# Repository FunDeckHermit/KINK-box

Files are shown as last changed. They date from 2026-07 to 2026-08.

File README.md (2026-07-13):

# KINK-box

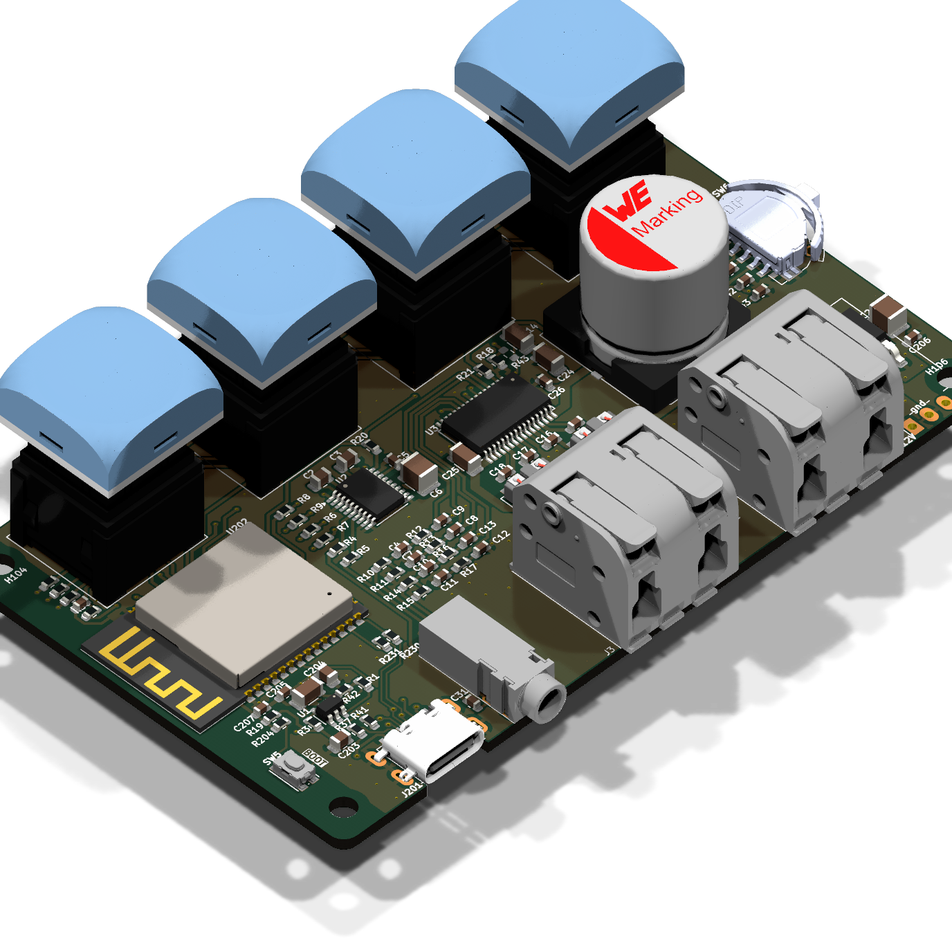
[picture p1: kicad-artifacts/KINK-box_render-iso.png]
KINK-box Isometric Render


A compact USB-C-powered stereo audio player and amplifier powered by an ESP32-S3 microcontroller.

## Overview

KINK-box is a dedicated audio playback device with built-in amplification, WiFi connectivity, and a simple web interface. Stream audio to speakers or headphones with intuitive physical and web controls.

## Features

- **USB-C Power Delivery**: Powered by standard USB-C PD adapter (12V negotiated)
- **WiFi Connectivity**: Built-in 2.4 GHz WiFi for streaming
- **Web Interface**: Control playback and configuration from any browser
- **Stereo Audio Output**: 
  - Speaker terminals for direct loudspeaker connection
  - 3.5mm line-level jack for headphones or external amplifiers
- **Physical Controls**: 
  - Four RGB-illuminated buttons for quick access
  - Additional tactile button and navigation switch for volume and menu control
- **Class-D Amplifier**: High-efficiency 30W stereo amplifier built-in

## Quick Start

1. **Assembly**: Reference the component placement guide and [Bill of Materials](kicad-artifacts/KINK-box_bom.csv)
2. **Power On**: Connect a USB-C Power Delivery adapter
3. **Connect**: Join the device WiFi network
4. **Access**: Open `http://<device-ip>` in your browser
5. **Play**: Use the web interface or physical buttons to select and play audio
6. **Volume**: Adjust using physical controls or the web interface

## Hardware Files

All manufacturing and design files are in `kicad-artifacts/`:
- **Gerbers**: `KINK-box_gerbers.zip` - For PCB fabrication
- **Schematics**: `KINK-box_schematic.pdf`
- **3D Model**: `KINK-box_board.step`
- **Interactive BOM**: `ibom.html`

## License

Apache License 2.0 - see [LICENSE](LICENSE) for details.

---

**KINK-box** - Simple stereo audio player with built-in amplification and WiFi.

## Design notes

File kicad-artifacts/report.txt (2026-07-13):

KiCad Export Report
===================

Project: KINK-box
Run at: 2026-07-13 19:25:50
Duration: 31s
KiCad Type: Flatpak

Render settings:
  Quality: high
  Resolution: 1400x1400
  Isometric rotation: 315,0,45

Gerber layers:
  F.Cu,B.Cu,F.Mask,B.Mask,F.Paste,B.Paste,F.SilkS,B.SilkS,Edge.Cuts

Drill:
  Format: Excellon
  Map: PDF

Placement:
  Format: CSV
  Units: mm
  Side: both

Interactive BOM:
  Fields: Value, Footprint, MF, MPN
  Grouped by: Value, Footprint
  DNP filtering: Enabled (kicad_dnp field)
  Layout: left-right
  Layer view: Front

Generated files:
build.log
drill
ibom.html
KINK-box_board.step
KINK-box_bom.csv
KINK-box_gerbers.zip
KINK-box_pcb.pdf
KINK-box_placement.csv
KINK-box_render-bottom.png
KINK-box_render-iso.png
KINK-box_render-top.png
KINK-box_schematic.pdf

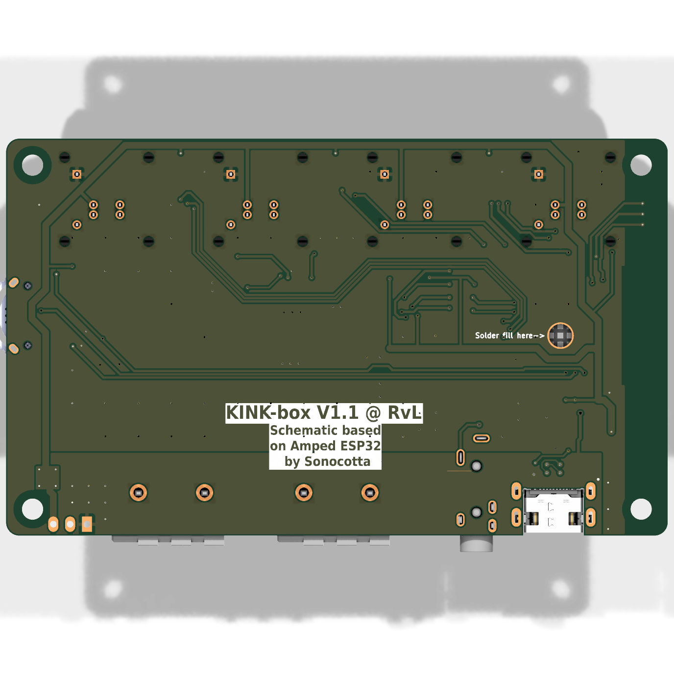
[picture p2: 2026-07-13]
kicad-artifacts/KINK-box_render-bottom.png

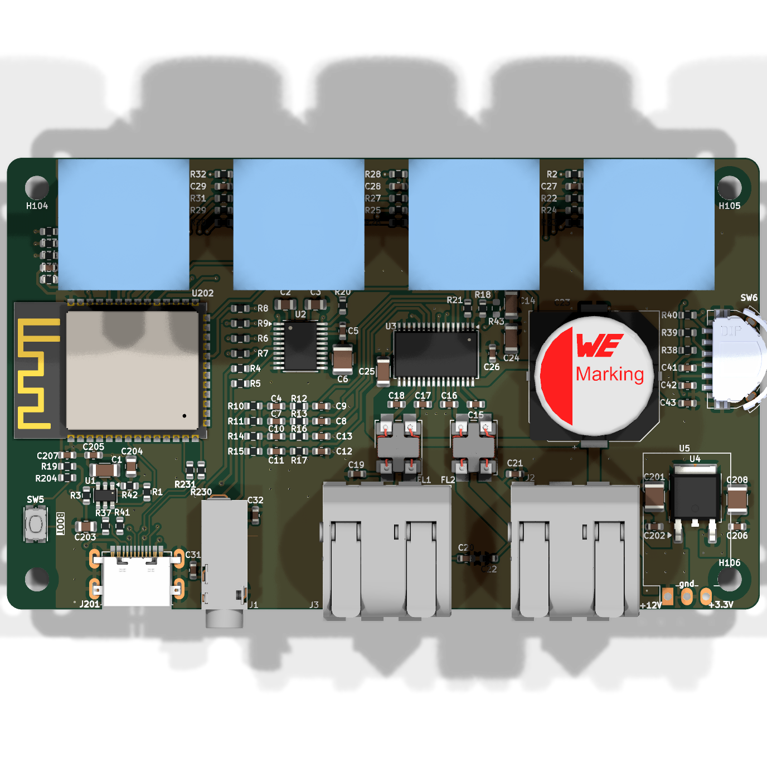
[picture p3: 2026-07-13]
kicad-artifacts/KINK-box_render-top.png

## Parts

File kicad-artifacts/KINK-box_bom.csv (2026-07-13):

Designator | Comment | MPN | Footprint | Quantity
C1,C4,C7,C10,C11,C14 | 1uF | 0603B105K100CT,1206B105K250CT | Capacitor_SMD:C_0603_1608Metric,Capacitor_SMD:C_1206_3216Metric | 6
C2,C3 | 2.2uF | 0805B225K250CT | Capacitor_SMD:C_0805_2012Metric | 2
C5,C15,C16,C17,C18,C26,C27,C28,C29,C30,C41,C42,C43,C202,C205,C206,C207 | 100nF | 0603B104K500CT | Capacitor_SMD:C_0603_1608Metric | 17
C6,C24,C25,C201,C203,C204,C208 | 10uF | 1206B106K250CT | Capacitor_SMD:C_0805_2012Metric,Capacitor_SMD:C_1206_3216Metric,Capacitor_SMD:C_1210_3225Metric | 7
C8,C9,C12,C13 | 220nF | 0603B224K500CT | Capacitor_SMD:C_0603_1608Metric | 4
C19,C20,C21,C22 | 680nF | 0603B684K100CT | Capacitor_SMD:C_0603_1608Metric | 4
C23 | 470uF | 865060663013 | 0_NRD_footprints:CP_Wurth_WCAP-ASLL-D16L17 | 1
C31,C32 | 2.2nF | 0603B222K500CT | Capacitor_SMD:C_0603_1608Metric | 2
FL1,FL2 | 744238701 | 744238701 | 0_NRD_footprints:L_Wurth_WE-CMDC-7060 | 2
H103,H104,H105,H106 | MountingHole |  | MountingHole:MountingHole_3.2mm_M3 | 4
J1 | PJ-328A0-B | PJ-328A0-B | 0_NRD_footprints:PJ-328A0-B | 1
J2,J3 | QT02CSF83H0000G | QT02CSF83H0000G | 0_NRD_footprints:QT02CSF83H0000G | 2
J201 | USB4500-03-0-A |  | _projectlib:USB_C_Receptacle_USB4500-03-0-A | 1
R1,R2,R3,R28,R32,R36,R38,R39,R40 | 47K | RC0603FR-0747KL | Resistor_SMD:R_0603_1608Metric | 9
R4,R5,R6,R7,R8 | 470R | RC0603FR-07470RL | Resistor_SMD:R_0603_1608Metric | 5
R9,R10,R11,R14,R15 | 10K | RC0603FR-0710KL | Resistor_SMD:R_0603_1608Metric | 5
R12,R13,R16,R17,R204 | 1K0 | RC0603FR-07FRE131KL | Resistor_SMD:R_0603_1608Metric | 5
R18 | 5K6 | RC0603FR-075K6L | Resistor_SMD:R_0603_1608Metric | 1
R19,R20,R21 | 22K | RC0603FR-0722KL | Resistor_SMD:R_0603_1608Metric | 3
R22,R23,R24,R25,R26,R27,R29,R30,R31,R33,R34,R35 | 220R | RC0603FR-07220RL | Resistor_SMD:R_0603_1608Metric | 12
R37,R41,R42 | 5K1 | RC0603FR-075K1L | Resistor_SMD:R_0603_1608Metric | 3
R230,R231 | 22R |  | Resistor_SMD:R_0603_1608Metric | 2
SW1,SW2,SW3,SW4 | 465M111172501 |  | 0_NRD_footprints:SW_Wurth_WS-PBTL_465M111172501 | 4
SW5 | KMR223GLFG | KMR223GLFG | 0_NRD_footprints:SW_Push_1P1T_NO_CK_KMR2 | 1
SW6 |  | PLMG5-GH-V-T/R | 0_NRD_footprints:SW_PLMG5-GH | 1
U1 | CH221K |  | Package_TO_SOT_SMD:SOT-23-6 | 1
U2 | PCM5100A |  | Package_SO:TSSOP-20_4.4x6.5mm_P0.65mm | 1
U3 | TPA3118D2DAPR | TPA3118D2DAPR | Package_SO:HTSSOP-32-1EP_6.1x11mm_P0.65mm_EP5.2x11mm_Mask4.11x4.36mm | 1
U4 | BD33FC0FP | BD33FC0FP-E2 | Package_TO_SOT_SMD:TO-252-2 | 1
U202 | ESP32-S3-WROOM-1 |  | _projectlib:ESP32-S3-WROOM-1 | 1

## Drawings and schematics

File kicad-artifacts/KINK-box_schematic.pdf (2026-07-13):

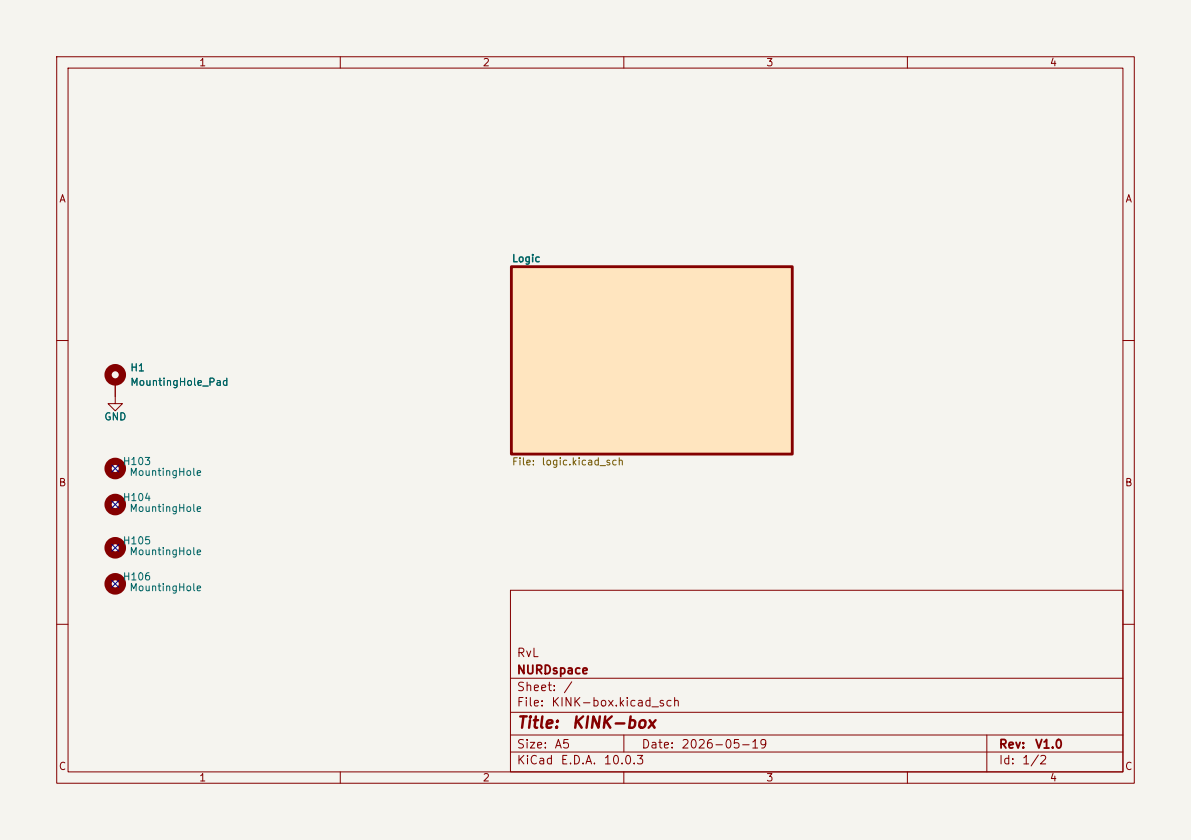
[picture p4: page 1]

File: logic.kicad_sch GNDH105 MountingHole H104 MountingHole H103 MountingHole H1MountingHole_Pad H106 MountingHole

Size: A5 | Rev: V1.0 | C Date: 2026-05-19
KiCad E.D.A. 10.0.3 | Id: 1/2

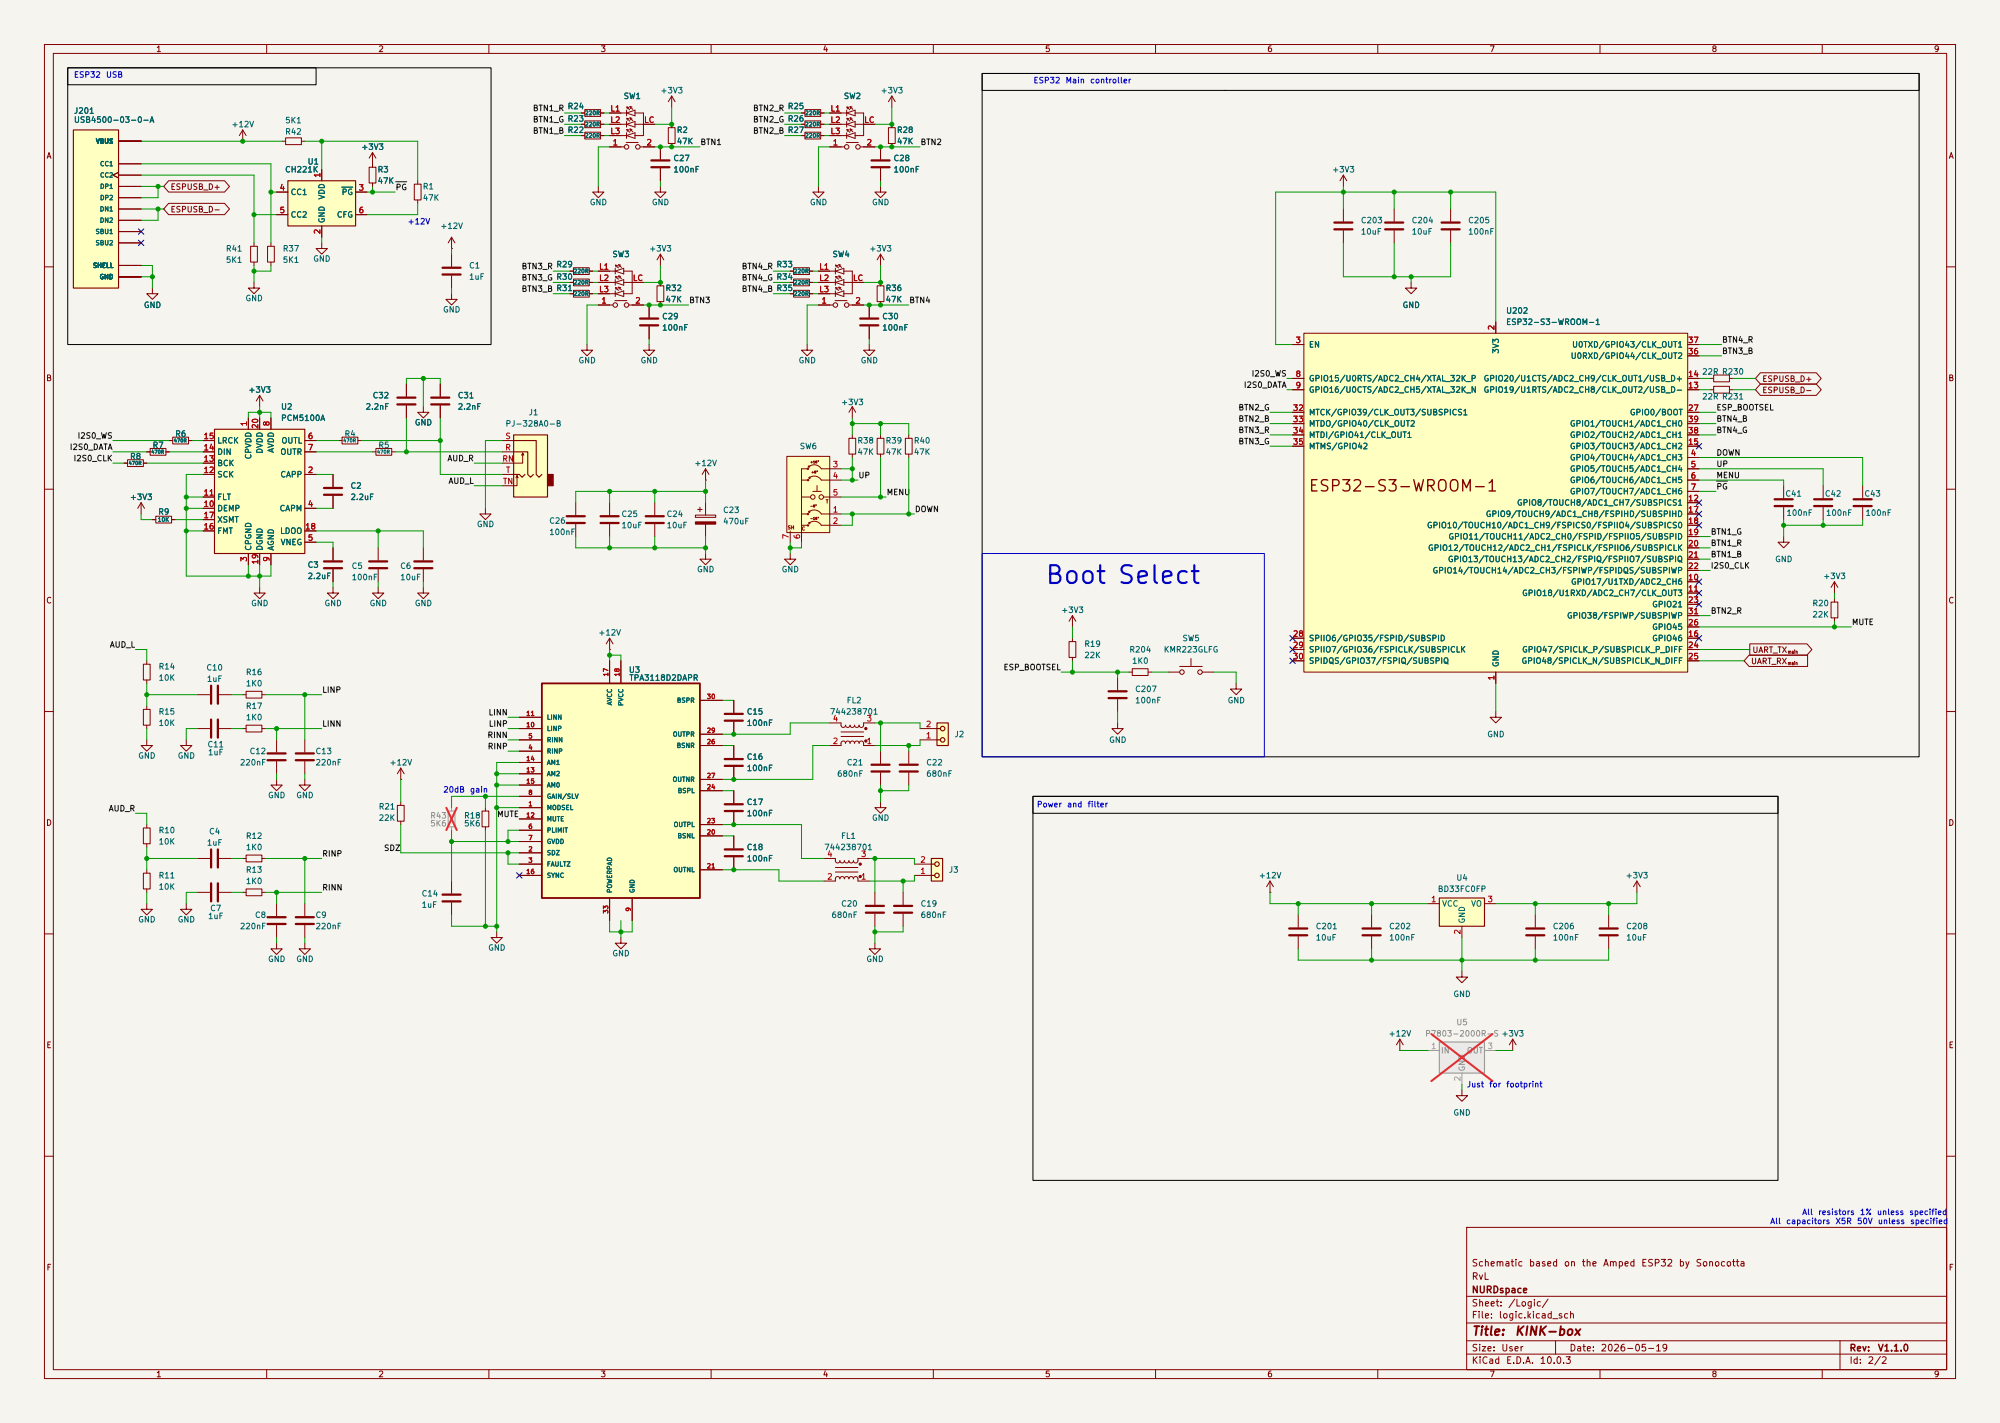
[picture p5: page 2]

ESP32 Main controller Boot Select

SCK 12 BCK 13 DIN 14 LRCK 15

All capacitors X5R 50V unless specified C18

Schematic based on the Amped ESP32 by Sonocotta
RvL
NURDspace
Sheet: /Logic/
File: logic.kicad_sch
Title: KINK-box

Size: User | Rev: V1.1.0
KiCad E.D.A. 10.0.3 | Id: 2/2

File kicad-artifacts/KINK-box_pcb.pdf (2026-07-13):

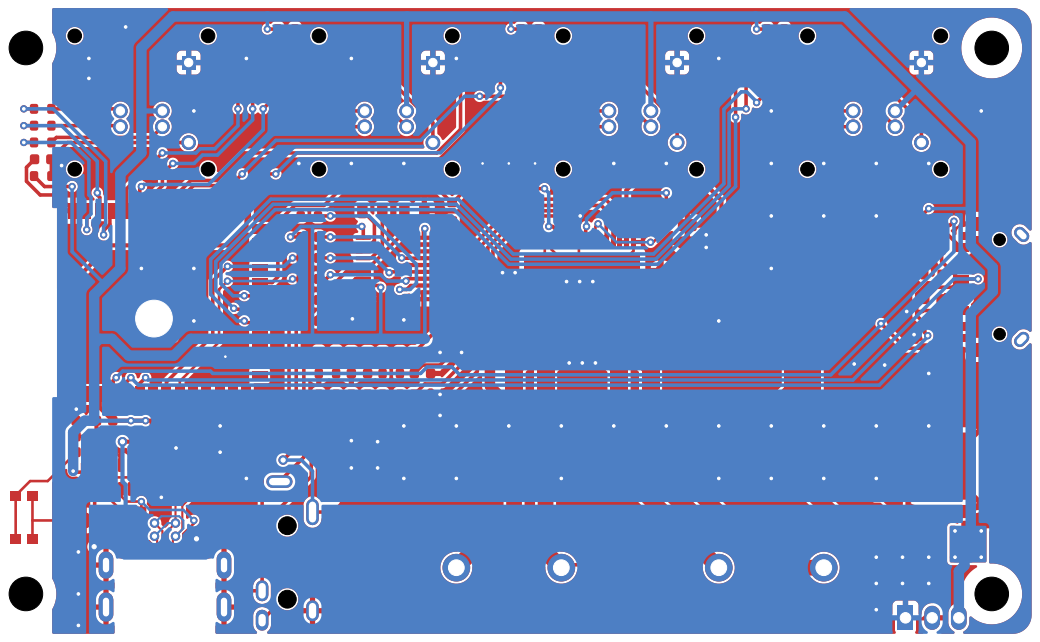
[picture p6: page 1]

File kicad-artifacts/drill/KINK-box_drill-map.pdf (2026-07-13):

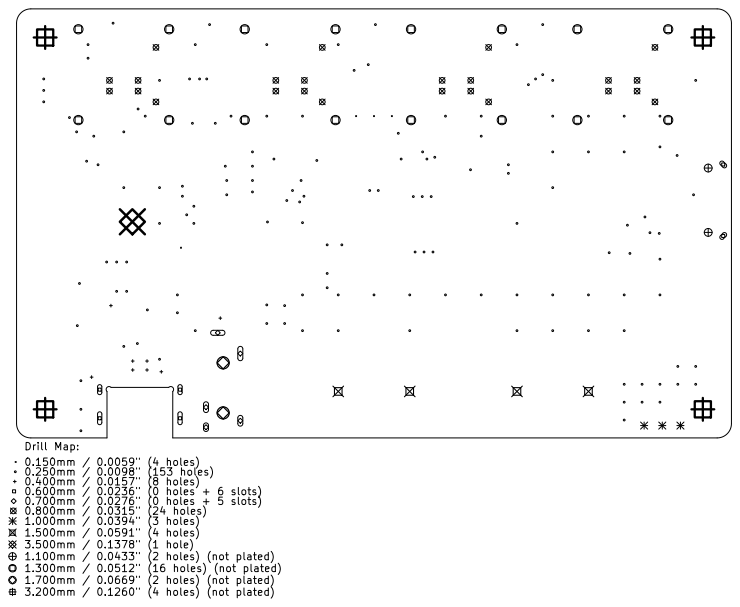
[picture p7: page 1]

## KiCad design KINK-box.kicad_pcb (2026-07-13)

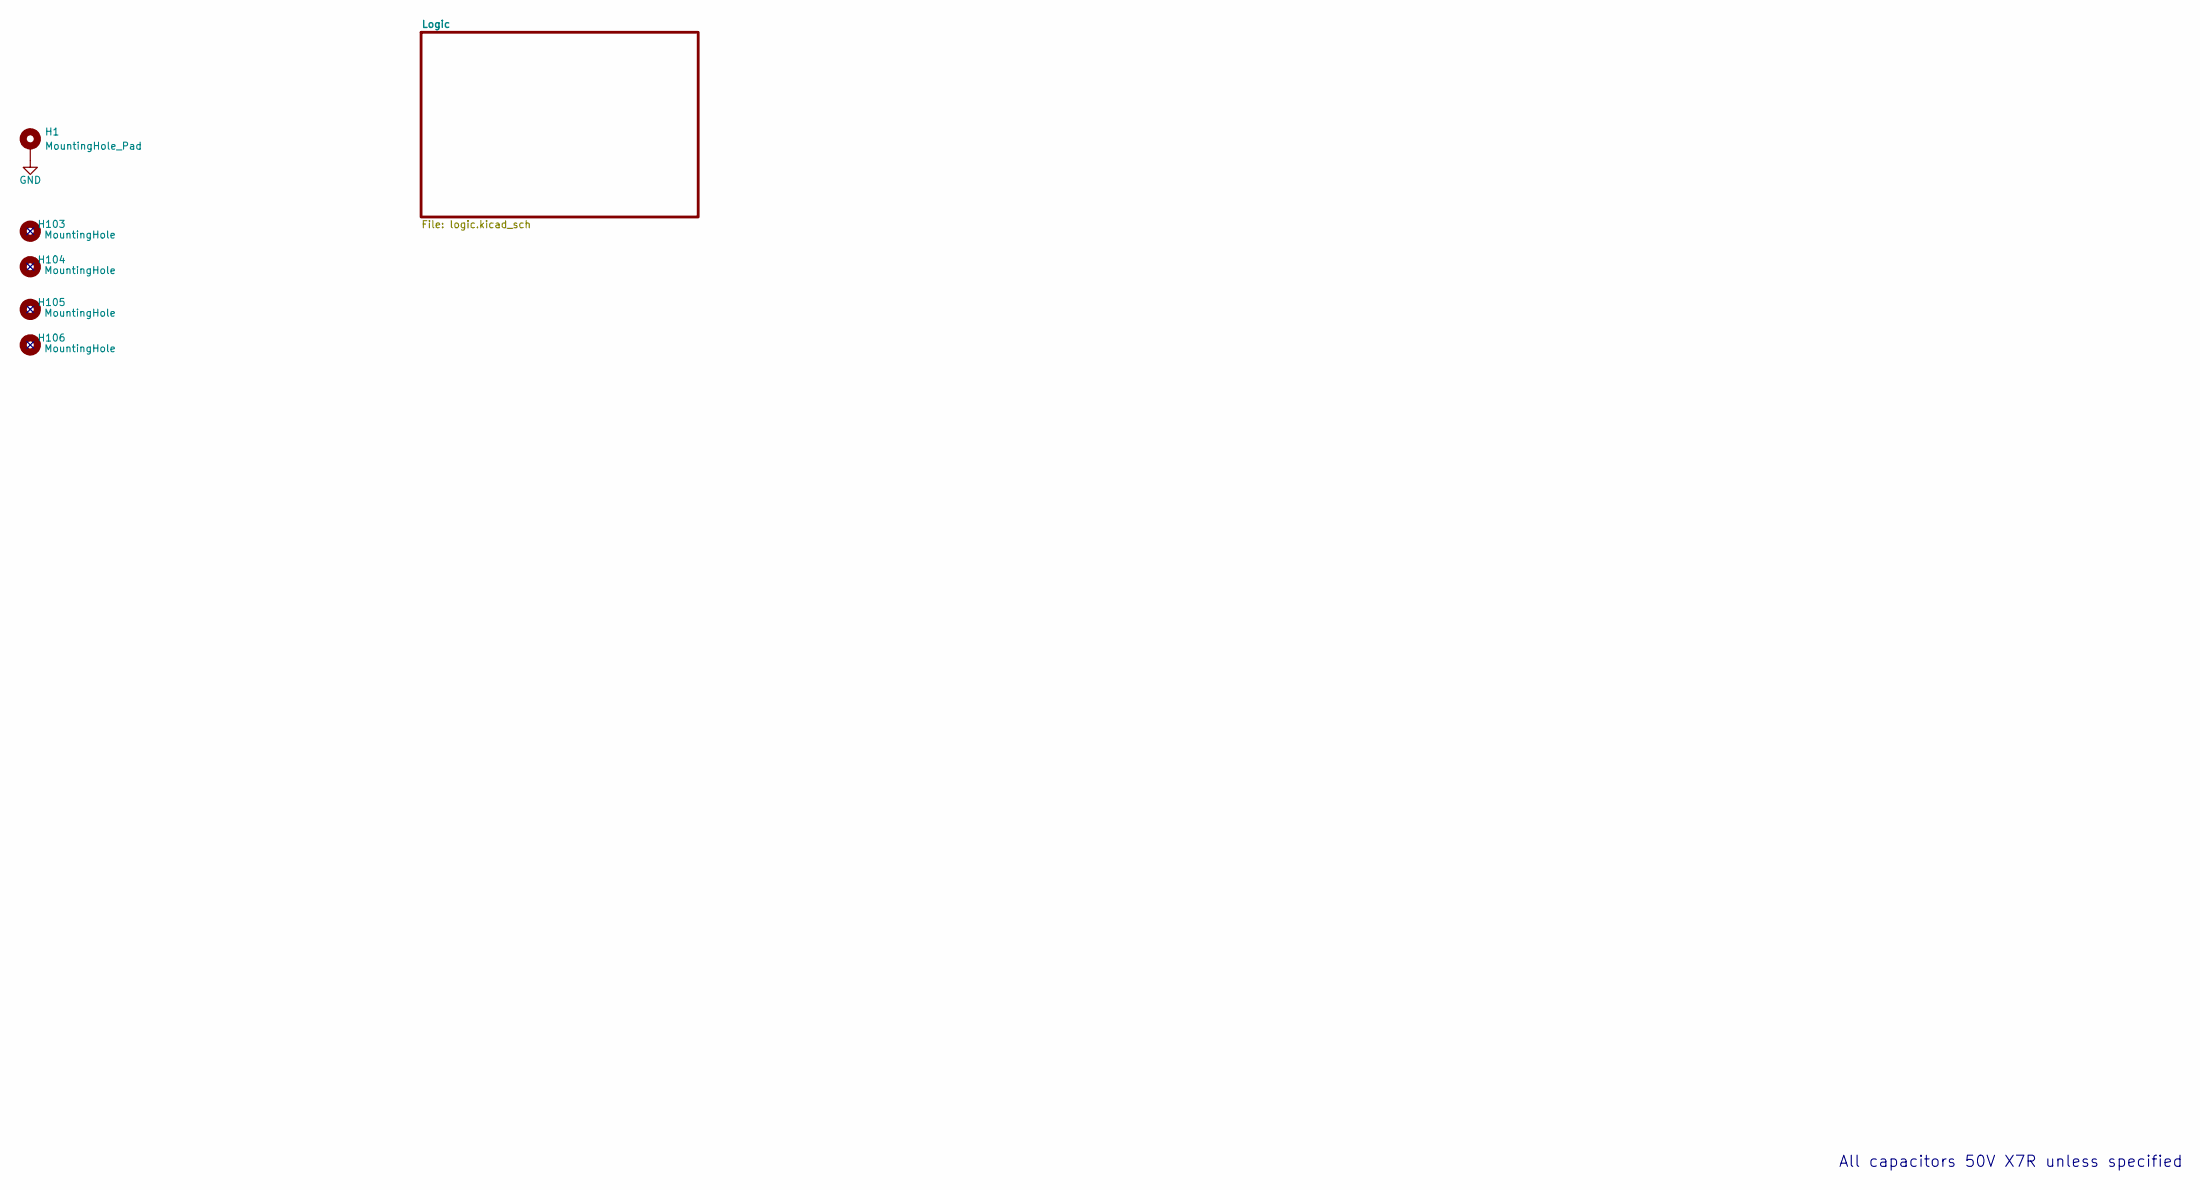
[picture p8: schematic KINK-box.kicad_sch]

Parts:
H1: MountingHole_Pad; ESP-solderhole
H103, H104, H105, H106: MountingHole; MountingHole_3.2mm_M3

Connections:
GND: H1.1 (1_1); also elsewhere on the board

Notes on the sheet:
All capacitors 50V X7R unless specified

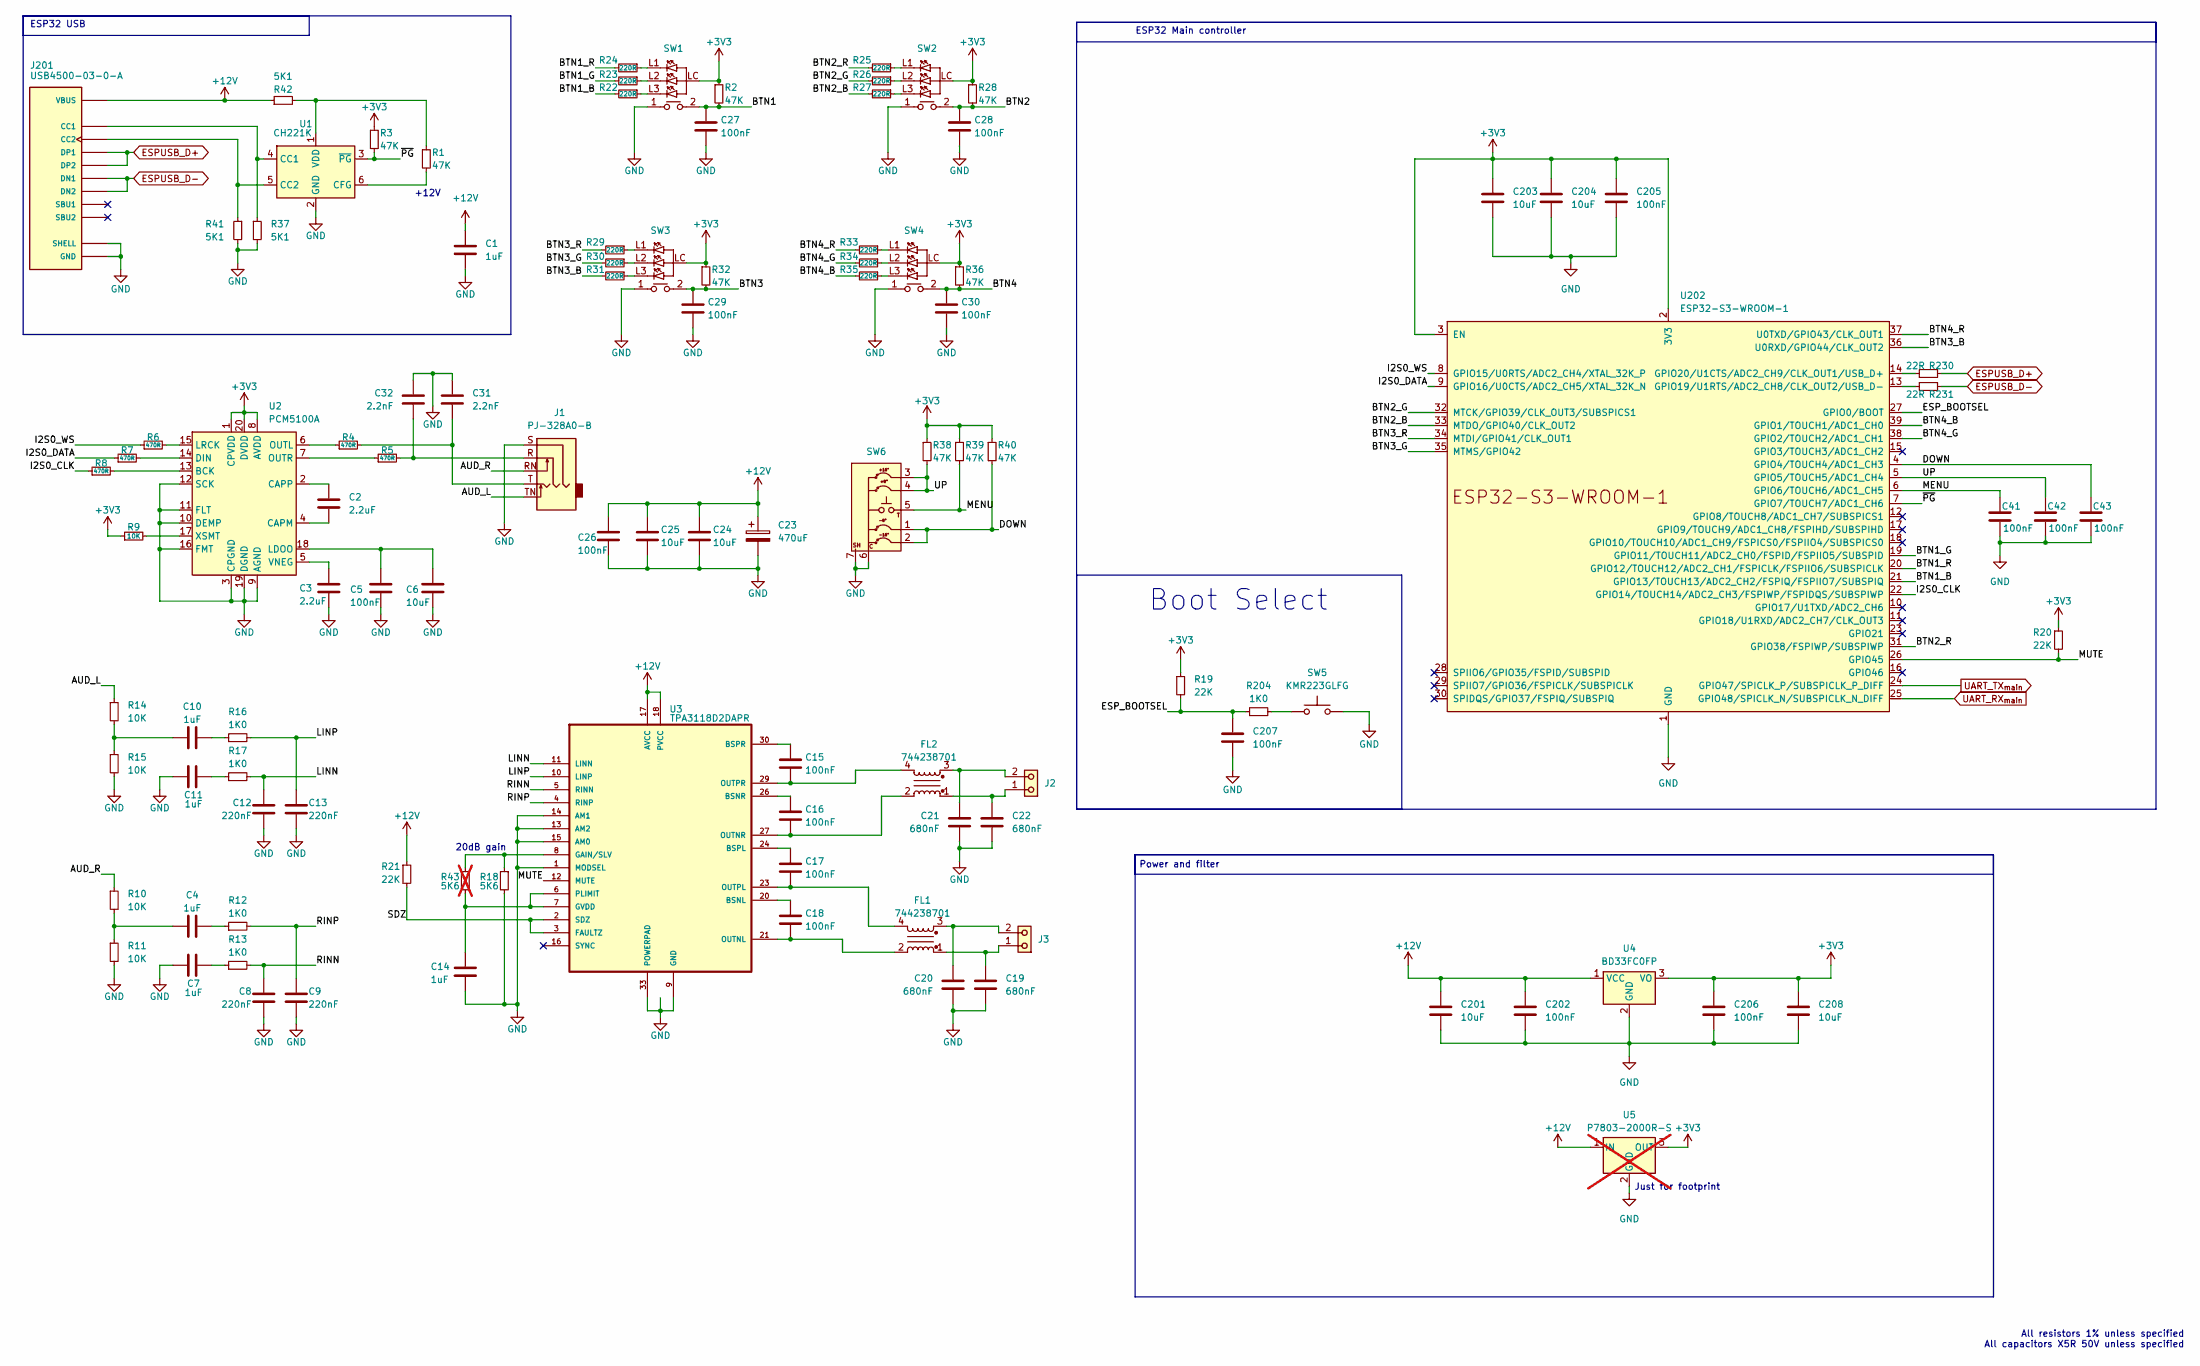
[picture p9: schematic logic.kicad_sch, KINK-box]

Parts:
C1, C14: 1uF; C_1206_3216Metric; Rated Voltage 25V; Tolerance ±10%; MPN 1206B105K250CT
C2, C3: 2.2uF; C_0805_2012Metric; Rated Voltage 25V; Tolerance ±10%; MPN 0805B225K250CT
C4, C7, C10, C11: 1uF; C_0603_1608Metric; Rated Voltage 10V; Tolerance ±10%; MPN 0603B105K100CT
C5, C15, C16, C17, C18, C26, C27, C28, C29, C30: 100nF; C_0603_1608Metric; Rated Voltage 50V; Tolerance ±10%; MPN 0603B104K500CT
C6, C201, C208: 10uF; C_1210_3225Metric
C8, C9, C12, C13: 220nF; C_0603_1608Metric; Rated Voltage 50V; Tolerance ±10%; MPN 0603B224K500CT
C19, C20, C21, C22: 680nF; C_0603_1608Metric; Rated Voltage 10V; Tolerance ±10%; MPN 0603B684K100CT
C23: 470uF; CP_Wurth_WCAP-ASLL-D16L17; MPN 865060663013
C24, C25: 10uF; C_1206_3216Metric; Rated Voltage 25V; Tolerance ±10%; MPN 1206B106K250CT
C31, C32: 2.2nF; C_0603_1608Metric; Rated Voltage 50V; Tolerance ±10%; MPN 0603B222K500CT
C41, C42, C43, C202, C205, C206, C207: 100nF; C_0603_1608Metric
C203, C204: 10uF; C_0805_2012Metric
FL1, FL2: 744238701; L_Wurth_WE-CMDC-7060; MPN 744238701
J1: PJ-328A0-B; MPN PJ-328A0-B
J2, J3: QT02CSF83H0000G; MPN QT02CSF83H0000G
J201: USB4500-03-0-A; USB_C_Receptacle_USB4500-03-0-A
R1, R2, R3, R28, R32, R36, R38, R39, R40: 47K; R_0603_1608Metric; MPN RC0603FR-0747KL
R4, R5, R6, R7, R8: 470R; R_0603_1608Metric; MPN RC0603FR-07470RL
R9, R10, R11, R14, R15: 10K; R_0603_1608Metric; MPN RC0603FR-0710KL
R12, R13, R16, R17: 1K0; R_0603_1608Metric; MPN RC0603FR-07FRE131KL
R18: 5K6; R_0603_1608Metric; MPN RC0603FR-075K6L
R19, R20, R21: 22K; R_0603_1608Metric; MPN RC0603FR-0722KL
R22, R23, R24, R25, R26, R27, R29, R30, R31, R33, R34, R35: 220R; R_0603_1608Metric; MPN RC0603FR-07220RL
R37, R41, R42: 5K1; R_0603_1608Metric; MPN RC0603FR-075K1L
R43: 5K6; R_0603_1608Metric; MPN RC0603FR-075K6L; not fitted
R204: 1K0; R_0603_1608Metric
R230, R231: 22R; R_0603_1608Metric
SW1, SW2, SW3, SW4: 465M111172501; SW_Wurth_WS-PBTL_465M111172501; Part Number 465M111172501
SW5: KMR223GLFG; SW_Push_1P1T_NO_CK_KMR2; MPN KMR223GLFG
SW6: SW_PLMG5-GH; MPN PLMG5-GH-V-T/R
U1: CH221K; SOT-23-6
U2: PCM5100A; TSSOP-20_4.4x6.5mm_P0.65mm
U3: TPA3118D2DAPR; HTSSOP-32-1EP_6.1x11mm_P0.65mm_EP5.2x11mm_Mask4.11x4.36mm; MPN TPA3118D2DAPR
U4: BD33FC0FP; TO-252-2; MPN BD33FC0FP-E2
U5: P7803-2000R-S; Converter_DCDC_RECOM_R-78HB-0.5L_THT; MPN P7805-2000R-S; not fitted
U202: ESP32-S3-WROOM-1

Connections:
+3V3: C203.1, C204.1, C205.1, C206.1, C208.1, R2.1, R3.1, R9.1, R19.1, R20.1, R28.1, R32.1, R36.1, R38.1, R39.1, R40.1, SW1.LC, SW2.LC, SW3.LC, SW4.LC, U2.1 (CPVDD), U2.8 (AVDD), U2.20 (DVDD), U4.3 (VO), U5.3 (OUT), U202.2 (3V3), U202.3 (EN)
+12V: C1.1, C23.1, C24.1, C25.1, C26.1, C201.1, C202.1, J201.A4 (VBUS), J201.A9 (VBUS), J201.B4 (VBUS), J201.B9 (VBUS), R21.1, R42.1, U3.17 (AVCC), U3.18 (PVCC), U3.19 (PVCC), U3.31 (PVCC), U3.32 (PVCC), U4.1 (VCC), U5.1 (IN)
/Logic/AUD_L: J1.TN, R14.1
/Logic/AUD_R: J1.RN, R10.1
/Logic/BTN1: C27.1, R2.2, SW1.2
/Logic/BTN1_B: R22.2, U202.21 (GPIO13/TOUCH13/ADC2_CH2/FSPIQ/FSPIIO7/S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)
/Logic/BTN1_G: R23.2, U202.19 (GPIO11/TOUCH11/ADC2_CH0/FSPID/FSPIIO5/S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)
/Logic/BTN1_R: R24.2, U202.20 (GPIO12/TOUCH12/ADC2_CH1/FSPICLK/FSPIIO6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)
/Logic/BTN2: C28.1, R28.2, SW2.2
/Logic/BTN2_B: R27.2, U202.33 (MTDO/GPIO40/CLK_OUT2)
/Logic/BTN2_G: R26.2, U202.32 (MTCK/GPIO39/CLK_OUT3/SUBSPICS1)
/Logic/BTN2_R: R25.2, U202.31 (GPIO38/FSPIWP/SUBSPIWP)
/Logic/BTN3: C29.1, R32.2, SW3.2
/Logic/BTN3_B: R31.2, U202.36 (U0RXD/GPIO44/CLK_OUT2)
/Logic/BTN3_G: R30.2, U202.35 (MTMS/GPIO42)
/Logic/BTN3_R: R29.2, U202.34 (MTDI/GPIO41/CLK_OUT1)
/Logic/BTN4: C30.1, R36.2, SW4.2
/Logic/BTN4_B: R35.2, U202.39 (GPIO1/TOUCH1/ADC1_CH0)
/Logic/BTN4_G: R34.2, U202.38 (GPIO2/TOUCH2/ADC1_CH1)
/Logic/BTN4_R: R33.2, U202.37 (U0TXD/GPIO43/CLK_OUT1)
/Logic/DOWN: C43.1, R40.2, SW6.1, SW6.2, U202.4 (GPIO4/TOUCH4/ADC1_CH3)
/Logic/ESP_BOOTSEL: C207.1, R19.2, R204.1, U202.27 (GPIO0/BOOT)
/Logic/I2S0_CLK: R8.1, U202.22 (GPIO14/TOUCH14/ADC2_CH3/FSPIWP/FSPIDQS/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)
/Logic/I2S0_DATA: R7.1, U202.9 (GPIO16/U0CTS/ADC2_CH5/XTAL_32K_N)
/Logic/I2S0_WS: R6.1, U202.8 (GPIO15/U0RTS/ADC2_CH4/XTAL_32K_P)
/Logic/LINN: C12.1, R17.2, U3.11 (LINN)
/Logic/LINP: C13.1, R16.2, U3.10 (LINP)
/Logic/MENU: C41.1, R39.2, SW6.5, U202.6 (GPIO6/TOUCH6/ADC1_CH5)
/Logic/MUTE: R20.2, U3.12 (MUTE), U202.26 (GPIO45)
/Logic/RINN: C8.1, R13.2, U3.5 (RINN)
/Logic/RINP: C9.1, R12.2, U3.4 (RINP)
/Logic/SDZ: R21.2, U3.2 (SDZ), U3.3 (FAULTZ)
/Logic/UP: C42.1, R38.2, SW6.3, SW6.4, U202.5 (GPIO5/TOUCH5/ADC1_CH4)
/Logic/~PG: R3.2, U1.3 (~PG), U202.7 (GPIO7/TOUCH7/ADC1_CH6)
ESPUSB_D+: J201.A6 (DP1), J201.B6 (DP2), R230.2
ESPUSB_D-: J201.A7 (DN1), J201.B7 (DN2), R231.2
GND: C1.2, C3.2, C5.2, C6.2, C7.1, C8.2, C9.2, C11.1, C12.2, C13.2, C14.2, C19.2, C20.2, C21.2, C22.2, C23.2, C24.2, C25.2, C26.2, C27.2, C28.2, C29.2, C30.2, C31.1, C32.1, C41.2, C42.2, C43.2, C201.2, C202.2, C203.2, C204.2, C205.2, C206.2, C207.2, C208.2, J1.S, J201.A1 (GND), J201.A12 (GND), J201.B1 (GND), J201.B12 (GND), J201.S1 (SHELL), R11.2, R15.2, R18.2, R37.2, R41.2, SW1.1, SW2.1, SW3.1, SW4.1, SW5.2, SW6.6, SW6.7, U1.2 (GND), U2.3 (CPGND), U2.9 (AGND), U2.10 (DEMP), U2.11 (FLT), U2.12 (SCK), U2.16 (FMT), U2.19 (DGND), U3.1 (MODSEL), U3.9 (GND), U3.13 (AM2), U3.14 (AM1), U3.15 (AM0), U3.22 (GND), U3.25 (GND), U3.28 (GND), U3.33 (POWERPAD), U4.2 (GND), U5.2 (GND), U202.1 (GND), U202.40 (GND), U202.41 (GND); also elsewhere on the board
unnamed: C4.1, R10.2, R11.1
unnamed: C4.2, R12.1
unnamed: C7.2, R13.1
unnamed: C10.1, R14.2, R15.1
unnamed: C10.2, R16.1
unnamed: C11.2, R17.1
unnamed: C19.1, FL1.1, J3.1
unnamed: C20.1, FL1.3, J3.2
unnamed: C21.1, FL2.3, J2.2
unnamed: C22.1, FL2.1, J2.1
unnamed: C31.2, J1.T, R4.2
unnamed: C32.2, J1.R, R5.2
unnamed: J201.A5 (CC1), R37.1, U1.4 (CC1)
unnamed: J201.B5 (CC2), R41.1, U1.5 (CC2)
unnamed: R204.2, SW5.1
unnamed: R22.1, SW1.L3 (BLUE)
unnamed: R23.1, SW1.L2 (GREEN)
unnamed: R24.1, SW1.L1 (RED)
unnamed: R27.1, SW2.L3 (BLUE)
unnamed: R26.1, SW2.L2 (GREEN)
unnamed: R25.1, SW2.L1 (RED)
unnamed: R31.1, SW3.L3 (BLUE)
unnamed: R30.1, SW3.L2 (GREEN)
unnamed: R29.1, SW3.L1 (RED)
unnamed: R35.1, SW4.L3 (BLUE)
unnamed: R34.1, SW4.L2 (GREEN)
unnamed: R33.1, SW4.L1 (RED)
unnamed: R1.2, U1.6 (CFG)
unnamed: R1.1, R42.2, U1.1 (VDD)
unnamed: R8.2, U2.13 (BCK)
unnamed: C2.2, U2.4 (CAPM)
unnamed: C2.1, U2.2 (CAPP)
unnamed: R7.2, U2.14 (DIN)
unnamed: C5.1, C6.1, U2.18 (LDOO)
unnamed: R6.2, U2.15 (LRCK)
unnamed: R4.1, U2.6 (OUTL)
unnamed: R5.1, U2.7 (OUTR)
unnamed: C3.1, U2.5 (VNEG)
unnamed: R9.2, U2.17 (XSMT)
unnamed: C18.1, U3.20 (BSNL)
unnamed: C16.1, U3.26 (BSNR)
unnamed: C17.1, U3.24 (BSPL)
unnamed: C15.1, U3.30 (BSPR)
unnamed: R18.1, R43.1, U3.8 (GAIN/SLV)
unnamed: C14.1, R43.2, U3.6 (PLIMIT), U3.7 (GVDD)
unnamed: C18.2, FL1.2, U3.21 (OUTNL)
unnamed: C16.2, FL2.2, U3.27 (OUTNR)
unnamed: C17.2, FL1.4, U3.23 (OUTPL)
unnamed: C15.2, FL2.4, U3.29 (OUTPR)
unnamed: R231.1, U202.13 (GPIO19/U1RTS/ADC2_CH8/CLK_OUT2/USB_D-)
unnamed: R230.1, U202.14 (GPIO20/U1CTS/ADC2_CH9/CLK_OUT1/USB_D+)
UART_RX_{main}: U202.25 (GPIO48/SPICLK_N/SUBSPICLK_N_DIFF)
UART_TX_{main}: U202.24 (GPIO47/SPICLK_P/SUBSPICLK_P_DIFF)

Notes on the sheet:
+12V
ESP32 USB
Power and filter
20dB gain
All resistors 1% unless specified All capacitors X5R 50V unless specified
Just for footprint
Boot Select
ESP32 Main controller

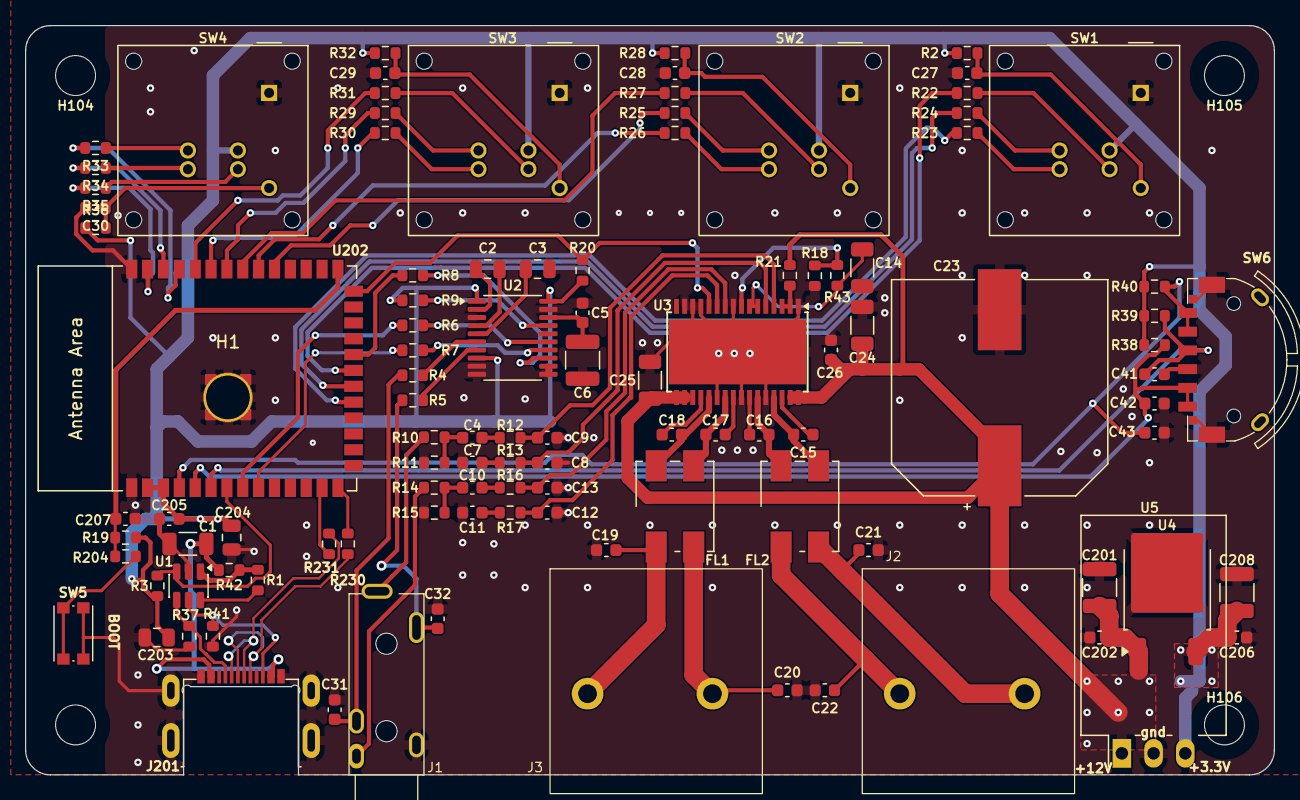
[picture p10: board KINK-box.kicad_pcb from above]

Board: 2 copper layers, 100.0 x 60.0 mm, 112 parts (0 on the bottom side), 88 nets.

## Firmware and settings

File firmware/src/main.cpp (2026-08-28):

#include <Arduino.h>
#include <WiFi.h>
#include "esp_heap_caps.h"
#include "AudioTools.h"
#include "AudioTools/Communication/HTTP/URLStream.h"
#include "AudioTools/AudioCodecs/CodecMP3Helix.h"
#include "Station.h" 

using namespace audio_tools;
const size_t SLIDING_WINDOW_SIZE = 1024 * 32; 

// Memory wraps redirecting TLS, tasks, and sockets to Octal PSRAM
extern "C" {
    void *__real_malloc(size_t s); void *__wrap_malloc(size_t s) { if (s > 48) { void *p = heap_caps_malloc(s, MALLOC_CAP_SPIRAM|MALLOC_CAP_8BIT); if (p) return p; } return heap_caps_malloc(s, MALLOC_CAP_INTERNAL|MALLOC_CAP_8BIT); }
    void *__real_calloc(size_t n, size_t s); void *__wrap_calloc(size_t n, size_t s) { size_t t = n * s; if (t > 48) { void *p = heap_caps_malloc(t, MALLOC_CAP_SPIRAM|MALLOC_CAP_8BIT); if (p) { memset(p, 0, t); return p; } } void *p = heap_caps_malloc(t, MALLOC_CAP_INTERNAL|MALLOC_CAP_8BIT); if (p) memset(p, 0, t); return p; }
    void *mbedtls_calloc(size_t n, size_t s) { return __wrap_calloc(n, s); } void mbedtls_free(void *p) { heap_caps_free(p); }
    BaseType_t __real_xTaskCreate(TaskFunction_t c, const char *n, uint32_t d, void *p, UBaseType_t pr, TaskHandle_t *t);
    BaseType_t __wrap_xTaskCreate(TaskFunction_t c, const char *n, uint32_t d, void *p, UBaseType_t pr, TaskHandle_t *t) {
        if (n != NULL && (strstr(n, "Audio") != NULL || strstr(n, "Buffer") != NULL || strstr(n, "URL") != NULL || strstr(n, "Pump") != NULL)) {
            return xTaskCreatePinnedToCoreWithCaps(c, n, d, p, pr, t, 0, MALLOC_CAP_SPIRAM);
        }
        return __real_xTaskCreate(c, n, d, p, pr, t);
    }
}


// Macro to print current free internal SRAM and external PSRAM
#define PRINT_RAM(label) do { \
    Serial.printf("=== RAM: %s ===\n", label); \
    Serial.printf("  Internal SRAM Free : %u Bytes\n", ESP.getFreeHeap()); \
    Serial.printf("  External PSRAM Free: %u Bytes\n\n", ESP.getFreePsram()); \
} while(0)


// Unified array defining your radio station lineup
RadioStation stations[] = {
    {"KINK BASE",       "https://playerservices.streamtheworld.com/api/livestream-redirect/KINK.mp3",         nullptr, nullptr},
    {"KINK DNA",        "https://playerservices.streamtheworld.com/api/livestream-redirect/KINK_DNA.mp3",         nullptr, nullptr},
    {"KINK DISTORTION", "https://playerservices.streamtheworld.com/api/livestream-redirect/KINK_DISTORTION.mp3",  nullptr, nullptr},
    {"KINK 90S",        "https://playerservices.streamtheworld.com/api/livestream-redirect/KINK_90S.mp3",         nullptr, nullptr}
};
const int STATIONS_COUNT = sizeof(stations) / sizeof(stations[0]);

I2SStream i2s;
VolumeStream volume(i2s);
MP3DecoderHelix mp3;
EncodedAudioStream decoder(&volume, &mp3);

volatile int station_idx = 0;
int active_playing_idx = -1; 
volatile uint32_t lastButton = 0;
TaskHandle_t pumpTaskHandle = NULL; 


void IRAM_ATTR menuISR() {
    uint32_t now = millis();
    if (now - lastButton > 250) {
        station_idx = (station_idx + 1) % STATIONS_COUNT;
        lastButton = now;
    }
}

void networkPumpTask(void *p) {
    while (true) {
        if (WiFi.status() == WL_CONNECTED) { 
            for (int i = 0; i < STATIONS_COUNT; i++) {
                if (stations[i].streamObj != nullptr && stations[i].slidingBuffer != nullptr) {
                    stations[i].pump();
                }
            }
        }
        vTaskDelay(pdMS_TO_TICKS(1)); 
    }
}


void delayedLoaderTask(void *p) {
    vTaskDelay(pdMS_TO_TICKS(2000));
    Serial.println("[LOADER] Initializing secondary radio channels in background...");
    for (int i = 1; i < STATIONS_COUNT; i++) {
        stations[i].init(i, SLIDING_WINDOW_SIZE, &decoder);
        stations[i].streamObj->begin(stations[i].url, "audio/mpeg");
        vTaskDelay(pdMS_TO_TICKS(500)); 
    }
    vTaskDelete(NULL); 
}

void setup() {
    Serial.begin(115200); delay(1000);
    AudioLogger::instance().begin(Serial, AudioLogger::Warning); 
    pinMode(MENU_PIN, INPUT_PULLUP); attachInterrupt(MENU_PIN, menuISR, FALLING);

    auto cfg = i2s.defaultConfig(TX_MODE);
    cfg.pin_bck = PIN_I2S_SCK; cfg.pin_ws = PIN_I2S_FS; cfg.pin_data = PIN_I2S_SD;
    cfg.buffer_size = 512; cfg.buffer_count = 4;
    i2s.begin(cfg); volume.setVolume(0.20); decoder.begin();

    WiFi.begin(WIFI_SSID, WIFI_PASS);
    while (WiFi.status() != WL_CONNECTED) { delay(500); Serial.print("."); }
    Serial.println("\nNetwork Ready!");

    stations[0].init(0, SLIDING_WINDOW_SIZE, &decoder);
    stations[0].streamObj->begin(stations[0].url, "audio/mpeg");
    Serial.printf("[INIT] Immediate Online Buffer for Main Station: %s\n", stations[0].name);

    xTaskCreatePinnedToCore(networkPumpTask, "NetPump", 4096, NULL, 1, &pumpTaskHandle, 0);
    xTaskCreatePinnedToCore(delayedLoaderTask, "DelayedLoad", 16384, NULL, 1, NULL, 0);
}

void loop() {
    stations[station_idx]->play();
}

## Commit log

2026-07-12 Fixed some meta-data
    [KINK-box.kicad_sch, logic.kicad_sch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]
2026-07-12 Add 12V USB Power Delivery and menu button volume control details
2026-07-12 Update README: Add aux output and RGB button features with TPA3118D2DAPR amplifier
2026-07-12 Fixed board edges
    [KINK-box.kicad_pcb, KINK-box.kicad_sch, KINK-box_placement.csv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]
2026-07-13 Fixed CH211 circuit and TPA3118D2 bugs
    [KINK-box.kicad_pcb, KINK-box_bom.csv, KINK-box_placement.csv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]
2026-08-27 Added firmware to switch between channels
2026-08-27 Instant switching on internal RAM
2026-08-28 Instant switching 3 stations
2026-08-28 Almost perfect switching
2026-08-28 Fixed some threading bugs
    [main.cpp]
